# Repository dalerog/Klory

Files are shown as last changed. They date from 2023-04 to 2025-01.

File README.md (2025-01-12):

# Klory
A variation of the Klor keyboard by GEIGEIGEIST (https://github.com/GEIGEIGEIST/KLOR).

***

Finished Klory

## Introduction

This is a guide to my experiences buiding Klory, my variant of the Klor keyboard. This was my first keyboard build and GEIST did an outstanding job
documenting the build process in the GitHub repository. The changes I made were mainly due to my inexperince. Some were just personal preference 
differences.

Spoiler alert! I love Klory and am buiding a second for home.

## Thanks!

Of course, thanks to GEIST for making such a great keyboard. 

- Thanks to Char for leading me down the mechanical keyboard rabbit hole. 
- Thanks to Peter B. for help soldering diodes and hot swap sockets. 
- Thanks Harlan for expertise in all things maker.
- Thanks Rohit G for advice on standoffs.

## Why the Klor?

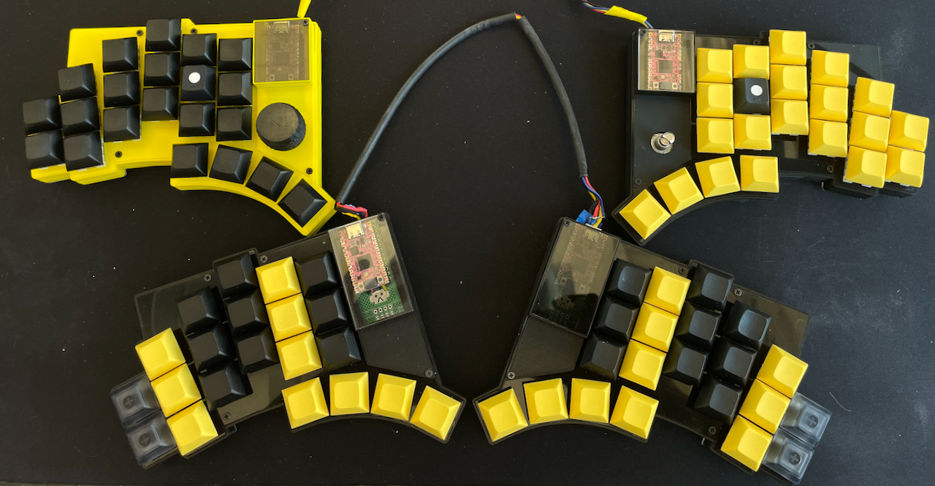
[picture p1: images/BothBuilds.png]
Both Builds


I was using a Planck Ez. I had changed the keymap to a 3x5 layout in which I was not using the center 6 keys above the spacebar. I was using the equivalent of four (4) thumb keys in my layout. However, I felt that my thumbs were cramped as they had to fold under my hand to get to some of the keys.

I really liked the Planck Ez, but then I started wanting a split keyboard. I originally looked for a split Planck, but then I thought column
stagger would be great and more room for my thumbs. I really liked the Corne, but I was using four thumb keys.

Therefore, the main reasons for the Klor were:
- four thumb keys
- thumb keys not requiring folding thumb under hand
- thumb keys in a curve

There were several nice to haves:
- encoder support
- the option of moving the pinkie out for the Q and P key instead of up.
- KB2040 support
- trackball support

I really wished the trackball was still for sale.

I was not interested in:
- OLED
- haptic feedback
- sound

These options did not seem that useful. Also, not all of the firmwares supported these different options.

I decided to built a wired Polydactyl using the Adafruit KB2040 without LEDs.

## Decisions

### Polydactyl

As I mentioned before, I picked the Klor for the four thumb keys. I was originally planning to build the Yubitsume layout without the extra pinkie keys. However, I was finding the pinkie reach to the P and the Q was not ideal. So, I decided to leave these keys on and experiment with using those keys as alternate pinkie keys. I have not started using these keys yet. Currently, I'm not interested in using these to give the pinkie more keys like return and delete etc. I'm more interested in fewer keys.

### LEDs

I really wanted the per key LEDs and partially decided on a wired solution to get the LEDs. However, after the initial excitment of having LEDs on the 
Planck, I decided that it didn't have a lot of value. I could't even see the leds in the lighting at work. I also wasn't sure which LEDs to order.

### Choc switches

The only negative at this point was that I wanted low profile Choc switches. I spent time looking for an alternative to the Klor that was low profile.
There were some teasers that there might be a low profile Choc variant. However, this did not seem likely or to happen in the timeframe I was willing to wait. I ended up decided that using MX switches allowed me to use the MX DSA keycaps that I had purchased for the Planck. I'm really happy that I went with MX switches because it gave me much more flexibility to test switches on the Planck.

### Why wired?

As a first build, I thought that a wired solution would be easier to debug and would have less failure modes. It would also work with QMK which I was used to using with the Planck. In addition, there were more options for MCUs and they would be cheaper.

There are cases where the right keyboard stops communicating with the left. Since, the keyboards are wired, I can just unplug them. I use a magnetic USB adapter so this is super easy to do. 

### KB2040

I decided to use the KB2040 from Adafruit. I picked it because it was cheap and and seemed very versatile. It worked with CircuitPython, C++, and Rust. It also had extra connectors, debug pins, LEDs, and reboot/reset buttons. It would be a great MCU for other projects if the keyboard didn't work out.

***

## Parts

Information about the parts I used and where I bought them is on the [Parts page](/pages/Parts.md).

## Build

Details about building my Klor keyboard are on the [Build page](/pages/Build.md).

## Building the Case

Details about building the case are on the [Case Build page](/pages/CaseBuild.md)

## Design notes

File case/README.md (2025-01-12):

# Case Source Files

This folder contains the files for building the case.

See case build documentation for more information.

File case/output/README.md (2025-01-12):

# STL Files for 3D Printing

This directory contains STL files for 3D printing that were exported from the OpenSCAD files in the parent directory.

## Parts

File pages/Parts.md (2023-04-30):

# Parts

Here is where I ordered the parts for my keyboard in the spring of 2023. This list will get stale overtime.

| Part Name | Vender | Notes |
| :--- | :--- | :--- |
| PCB  | [JLCPCB](https://jlcpcb.com) | I ordered a green PCB instead of a black one because it was 2+ days faster. Minimum order was 5. |
| MCU  | [Adafruit](https://www.adafruit.com/product/5302) | KB2040 |
| MX Key switch | Amazon | When you include shipping, you can get some better deals here than other vendors. But, I had to order 65. |
| switch socket | [Adafruit](https://www.adafruit.com/product/4958) | Kaihl Switch Socket|
| diodes 1N4148W| [Adafruit](https://www.adafruit.com/product/5099) | |
| 1u MX keycaps | [Adafruit](https://www.adafruit.com/product/4997) | DSA keycaps in multiple colors. |
| OLED module | N/A | Did not use. |
| reset button  | N/A | Did not use. The KB2040 has a reset button on it. Also, I was building a wired version and can just unplug it. |
| ~~TRRS jack~~ JST-SH Connector | [Adafruit](https://www.adafruit.com/product/4208) | Currently, hardwired, I have purchased this instead of TRRS. |
| ~~TRRS cable~~  JST-SH Cable | [Adafruit](https://www.adafruit.com/product/5385) | Currently, hardwired, but purchased this instead of TRRS. |
| EC11N1524402 encoder  | [Mouser](https://www.mouser.com/ProductDetail/Alps-Alpine/EC11N1524402?qs=W%2FMpXkg%252BdQ5mmk2EdvtXAA%3D%3D) | Planning to use this one, but have not installed it yet. |
| encoder knob  | N/A | Thinking of adapting the [Klotz Knob](https://github.com/GEIGEIGEIST/KLOTZ/tree/main/knob), but haven't yet. |
| USB cable | N/A | Using one I already had. I recommend a super flexible cable. Some usb-c video cables are too stiff. |

## OPTIONAL PARTS

I was going to use the pins that come with the KB2040 and these [headers from Adafruit](https://www.adafruit.com/product/598). However, I didn't think the combination worked that well. The headers while shorter than normal are still a little tall and the pins are a little long for them.

I ended up ordering these sockets from [TyperActive](https://typeractive.xyz/products/ez-machine-sockets-and-headers). They are expensive when you consider that the KB2040 itself is a $1 cheaper. However, they work well. I highly recommend getting sockets as I it nice being able to remove the MCU when you want to make a mod to your PCB. I was thinking that I could just unsolder the sockets if I wanted to move them to another board, but It isn't that easy to unsolder. I am a novive at desoldering though. Order a couple of extras and get free shipping.

## Case Parts

I printed my own 3D parts and cut my own acrylic. I ended up making very different cases which I will detail later. Here are the parts I ordered:

| Part Name | Vender | Notes |
| :--- | :--- | :--- |
| M2 Screws | [Amazon](https://a.co/d/6NNHfAM) | Lots of different sizes of screws gave me flexibilty when I designed my own case |
| Bass Standoffs in mutiple sizes | [Amazon](https://a.co/d/2GAflAl)  | |
| Bass Standoffs - 7mm | [Amazon](https://a.co/d/j9lGEjD)  | |

After I made my Amazon orders, I ended up finding standoffs at [Keeb.io](https://keeb.io/collections/diy-parts/products/m2-screws-and-standoffs). I haven't ordered these, but have ordered other items from Keeb.io.

***

[Back to Main Page](/README.md)

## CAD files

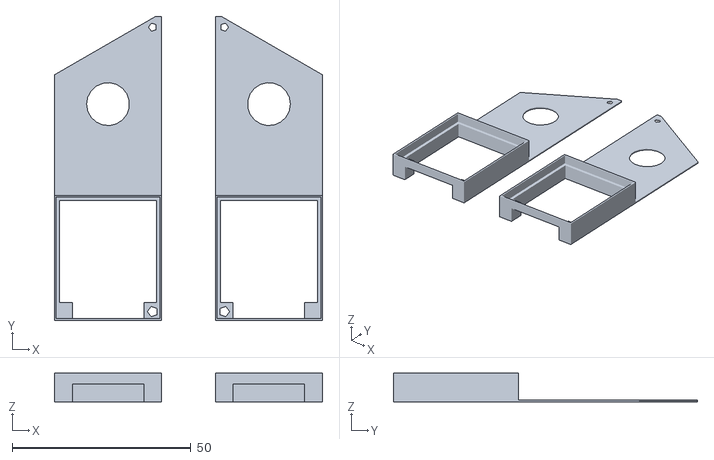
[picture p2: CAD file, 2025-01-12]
case/output/mcuCoverTopLessWithEncoder.stl
75.0 x 85.0 x 8.00

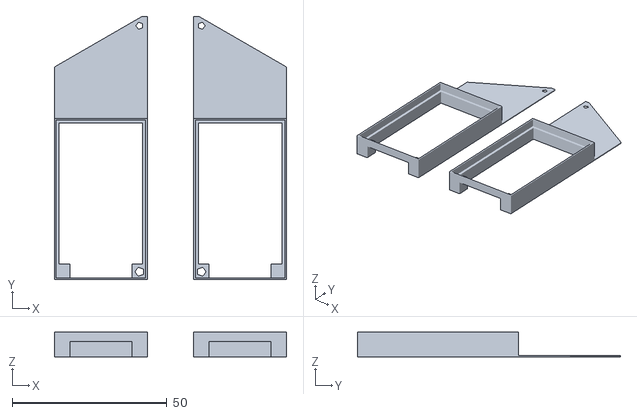
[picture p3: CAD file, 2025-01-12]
case/output/mcuCoverTopless.stl
75.0 x 85.0 x 8.00

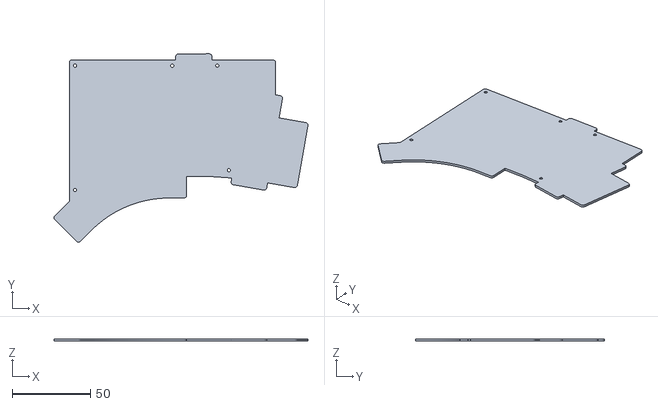
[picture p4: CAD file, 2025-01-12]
case/output/bottomPlate.stl
162.1 x 120.3 x 1.50

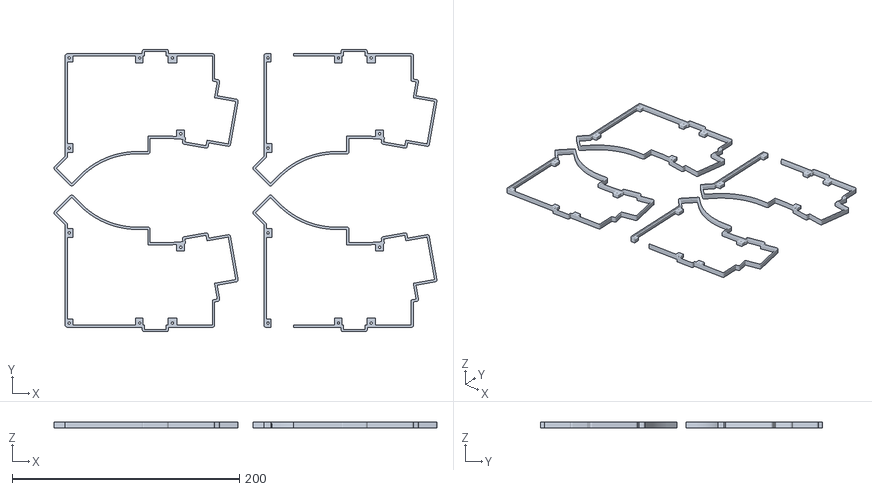
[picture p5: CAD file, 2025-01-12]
case/output/caseSides.stl
337.1 x 248.7 x 5.50

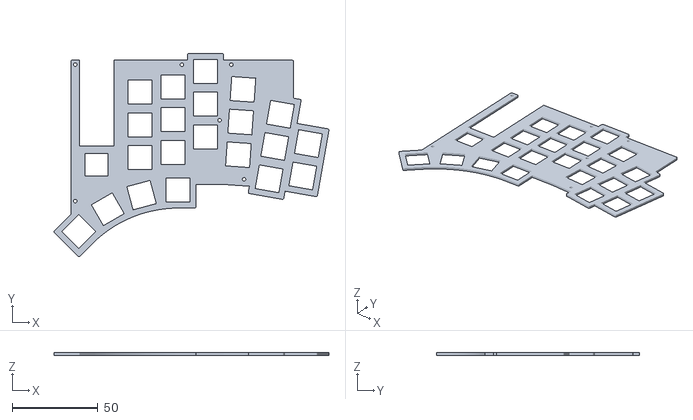
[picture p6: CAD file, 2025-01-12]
case/output/switchPlate.stl
160.0 x 118.2 x 1.50

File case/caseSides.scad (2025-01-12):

/* Copyright 2024
 * Dale Rogerson
 *
 * This program is free software: you can redistribute it and/or modify
 * it under the terms of the GNU General Public License as published by
 * the Free Software Foundation, either version 2 of the License, or
 * (at your option) any later version.
 *
 * This program is distributed in the hope that it will be useful,
 * but WITHOUT ANY WARRANTY; without even the implied warranty of
 * MERCHANTABILITY or FITNESS FOR A PARTICULAR PURPOSE.  See the
 * GNU General Public License for more details.
 *
 * You should have received a copy of the GNU General Public License
 * along with this program.  If not, see <http://www.gnu.org/licenses/>.
 */

//---  Top plate
module topPlate() {
    linear_extrude(height = 1.5)
    import("SwitchPlate.svg");
}

//---  Bottom plate
module bottomPlate() {
    linear_extrude(height = 1.5)
    import("BottomPlate.svg");
}

//---  Top outline
/*
linear_extrude(height = 1.5)
import("outerLip.svg");
*/

module rightSide() {
//--- Side
sideHeight = 4;
linear_extrude(height = sideHeight)
import("side.svg");

//  Lip from top outline
dY = 0.25;
lipHeight =  1.5 + dY;
lipZ = sideHeight - dY;
translate([0, 0, lipZ])
linear_extrude(height = lipHeight)
import("outerLip.svg");
}


module leftSide() {
    mirror([0, 1, 0]) {
        rightSide();
    }
}

//--- Make hole for the usb and keyboard connectors
module rightSideWithHole() {
    difference() {
        rightSide();
        translate([15, 108, -1]) cube([20, 15, 9]);
    }
}

module leftSideWithHole() {
    mirror([0, 1, 0]) {
        difference() {
            rightSide();
            translate([15, 108, -1]) cube([20, 15, 9]);
        }
    }
}

// Render the case for the right side with a hole for the connector.
rightSideWithHole();

// Uncomment this if you want to see how the bottom plate fits with the top plate.
// You can also print the bottom plate instead of cutting it out of acrylic with a laser cutter.
//bottomPlate();

// Uncomment to show top plate fitting on top of the case.
// You can also use this to print the top plate intead of cutting with a laser cutting. 
// Remove the translatoion for printing.
//translate([0, 0, 4]) topPlate();

translate([-175, 0, 0]) rightSide();


translate([0, -10, 0]) leftSideWithHole();
translate([-175, -10, 0]) leftSide();

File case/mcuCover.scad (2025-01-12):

/* Copyright 2024
 * Dale Rogerson
 *
 * This program is free software: you can redistribute it and/or modify
 * it under the terms of the GNU General Public License as published by
 * the Free Software Foundation, either version 2 of the License, or
 * (at your option) any later version.
 *
 * This program is distributed in the hope that it will be useful,
 * but WITHOUT ANY WARRANTY; without even the implied warranty of
 * MERCHANTABILITY or FITNESS FOR A PARTICULAR PURPOSE.  See the
 * GNU General Public License for more details.
 *
 * You should have received a copy of the GNU General Public License
 * along with this program.  If not, see <http://www.gnu.org/licenses/>.
 */


//---  Top plate
module topPlate() {
    linear_extrude(height = 1.5)
    import("top-thisIsSwitchPlate.svg");
}

// --- This mcu cover has a top on it and is the same height down the keyboard. I did not use
module mcuCover() {
     difference() {
        cube([30, 85, 5]); // main body
        translate([5, 0, 0]) cube([20, 60, 4]); // main hollow out
        translate([5, 0, 0]) cube([15, 70.75, 4]); // back middle hollow out
        translate([2, 7, 0]) cube([10, 71, 4]); // left wider hollow out
        translate([20, 7, 0]) cube([8, 60, 4]); // right wider hollow out
      
     color("green")
        translate([0, 86, 0])
            rotate([0, 0, -30])
                cube([40, 40, 5]); // trim end
    color("green") // front hole
        translate([2.5, 2.5, -5]) cylinder(h = 10, r = 1.2);
    color("green") // back hole
        translate([2.5, 2.5+79.5, -5]) cylinder(h = 10, r = 1.2);

    color("green") // light hole
        translate([10, 2.5, -5]) cylinder(h = 15, r = 1.2);
    color("green") // light hole
        translate([20, 2.5, -5]) cylinder(h = 15, r = 1.2);
    }
}


/* Uncomment these lines to use this alternative cover.
translate([5, 0, 5])
    rotate([0, 180, 0])
        mirror([1, 0, 0])
            mcuCover();
 

translate([-5, 0, 5])
    rotate([0, 180, 0])
        mcuCover();
*/  

topPlateHeight = 3.0;

mcuClearance = 5;
coverHeight = mcuClearance + topPlateHeight;

coverWidth = 30;
// coverLength = 52;

lipWidth = 0.5;
  
wideWallWidth = 5;
thinWallWidth = 1.5;

postOffset = 5;

//--- Make a cover that has minimal height and an opening to see MCU.
module mcuCoverTopless(CoverLength) {
    //  Front
    difference() {
        cube([coverWidth, CoverLength, coverHeight]); // front body
        
        translate([wideWallWidth, 0, 0])
            cube([coverWidth-wideWallWidth*2, CoverLength-thinWallWidth, mcuClearance]); // main hollow out
        
        translate([lipWidth, lipWidth, mcuClearance])
            cube([coverWidth-lipWidth*2, CoverLength-lipWidth*2, topPlateHeight]); // remove top

        translate([thinWallWidth, postOffset, 0])
            cube([5, CoverLength-thinWallWidth-postOffset, coverHeight]); // make outside wall narrower
            
        translate([coverWidth-postOffset-thinWallWidth, postOffset, 0])
            cube([5, CoverLength-thinWallWidth-postOffset, coverHeight]); // make inside wall narrower                
                
    color("green") // front hole for screw/support
        translate([2.5, 2.5, -5]) cylinder(h = 10, r = 1.5);

    }
    
    //  Back half
    difference() {
        color("blue") translate([0, CoverLength, 0]) cube([30, 52-CoverLength+33, .5]); // front body
        
      
     color("green")
        translate([0, 86, 0])
            rotate([0, 0, -30])
                cube([40, 40, 5]); // trim end

     color("green") // back hole
        translate([2.5, 2.5+79.5, -5]) cylinder(h = 10, r = 1.2);
                
    }
}


// --- Covers the hole in the top plate.
//
//     This can be cut on a laser cutter instead of 3D printed which is what I did.
module topInsert(CoverLength) {

    difference() {
        translate([lipWidth, lipWidth, mcuClearance])
            cube([coverWidth-lipWidth*2, CoverLength-lipWidth*2, topPlateHeight]); // remove top
        
        color("green") // front hole
            translate([2.5, 2.5, -5]) cylinder(h = 10, r = 1.2);
    }
};

coverLength = 52;

//
// These print without the holes for the encoder. 
//

// Left Cover
//mcuCoverTopless(coverLength);

// Right Cover
//translate([-coverWidth/2, 0, 0]) mirror([1, 0, 0]) mcuCoverTopless(coverLength);

// If you don't want to do that you can uncomment these lines and cover the hole in the
// MCU cover. You will need to adjust it to get it to work for both right and left covers and
// add screw holes.
// color("green") topInsert(coverLength); // This covers the hole in the mcu cover


coverLengthWithEncoder = 35;

module mcuCoverToplessEncoder() {
    difference() {
        mcuCoverTopless(coverLengthWithEncoder);

        // This is the hole for the encoder to poke through.
        color("green") // front hole
            translate([coverWidth/2, 60.5, -5]) cylinder(h = 10, r = 6);
    }        
}

//
// These print with the hole for the encoder. If you aren't using the encoder. Look above.
//

// Left cover
mcuCoverToplessEncoder();

// Right cover
translate([-coverWidth/2, 0, 0]) mirror([1, 0, 0]) mcuCoverToplessEncoder();

// I put clear or smokey arcylic over the MCU so that I can see it. Looks really cool.
// If you don't want to do that you can uncomment these lines and cover the hole in the
// MCU cover. You will need to adjust it to get it to work for both right and left covers
// and add screw holes.
// color("green") topInsert(coverLengthWithEncoder); // This covers the hole in the mcu cover


// put switch plate down to align the hole in the encoder.
/*
translate([-10, 114, 0]) {
    mirror([0, 1, 0]) {
        topPlate();
    }
 } 
 */
     
 

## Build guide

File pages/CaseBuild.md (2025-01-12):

# Building the Case

As you know from the other sections, I moved the position of the MCU from the bottom to the top of the PCB. This means that I have to change the case to
adjust to this change. There are a set of changes that need to be made to made the original case work with the moved MCU. These include moving the hole in
the case for the USB connector, covering up the holes for the Reset and TRRS, making a hole in the switchplate for the MCU, and covering the hole in the
bottom for the MCU to fit. In addition, the Klor case has a plate that fits over the switch plate. This plate will not fit over the MCU in the position on top.

However, I ended up with a bigger issue. It is probably either due to me doing something wrong or to the hotswap sockets that I used, but in my case build
the distance between the PCB and the switchplate was too small. The keyswitches would not fully snap into the switchplate. Also when you tried to pull the 
switches out, the switchplate would move up as you pulled up.

As a result, I essentially redesigned the case. 

## Overview

The new case is essentially a stack case and is a combination of 3D printed and laser cut. It ends up slightly smaller and shorter than the orginal case.

I limited myself to using the existing holes in the PCB and not drilling new holes. It would have been nice if the holes in the PCB were for M2 screws
instead of M2 standoffs, but we got it to work.

Here are the pieces to the case.

| Part | Build | Details | Notes |
| --- | --- | --- | --- |
| Bottom Plate | laser cut 1.6 mm acrylic or 3D printed | This piece is smaller than in the original Klor case. There are holes for M2 screws. | I laser cut mine from clear acrylic scrap |
| Side Plate no hole | 3D printed | There are holes for M2 standoffs 9mm. | It has an "h" profile for the PCB to rest on. |
| PCB | | The PCB also has holes for the M2 standoffs. | |
| Side Plate with hole | 3D printed | Hole is for the usb and TRRS connectors to go through | It also has an "h" profile for switchplate to rest on. |
| Switchplate | 1.6 mm acrylic or 3D printed | Have cutouts for the MCU to poke up through | I did both acrylic and 3D printing versions |
| MCU Cover Frame | 3D Printed | This is a frame to hole a cover for the MCU. It also covers the encoder hole. | |
| MCU Cover | Laser Cut | Covers the MCU. | You could 3D print this with the part abhove. |

The source files for building the case can be found in the case folder. 

* If you are laser cutting the switch plate (top) and bottom plate, you can use the files **BottomPlate.svg** and **SwitchPlate.svg**. 

* The file **caseSides.scad** is an OpenSCAD file for generating the STL files for 3D printing the case. This one file will generate the four parts of the case that are needed. You can comment out lines if you only want to print one part at a time. 

* The file **output/caseSides.stl** is the file for the 3D printer that was exported from **caseSides.scad**.

* If you want to 3D print the top and bottom plate instead of laser cutting them, you can uncomment lines in caseSides.scad to generate them. You can find the output for these in the files **case/switchPlate.stl** and **case/bottomPlate.stl**. I didn't use these files in my build and it is possible that the height of these files are not the same as the acrylic that I used, so it might take some adjustment to work.

* The file **mcuCover.scad** creates the cover for the MCU and encoder. There are multiple versions that you can create from this file depending on what you comment or uncomment. The file **case/mcuTopless.stl** is the output for a build without an encoder while **case/mcuTopLessWithEncoder.stl** is for builds with an encoder.

    * These version do not have covers over the MCU, but require an acrylic window. You can uncomment some lines in the scad file to get          covers 3D printed. You would need to add screw holes as I didn't add those. You can always use a drill to add them.
 
* If you are laser cutting acrylic for a window to see the MCU, use the files **mcuCoverInsert.svg** or **mcuCoverInsertWithEncoder.svg**. I used both clear and smoke acrylic and can't decide which looks better. Both look awesome!

***

## Building

| Parts for the case |
|:--:| 
| *Parts of the case except for the MCU cover.* |

The key design element of this case is that the distance between the PCB and the switchplate is fixed. The "h" shaped side pieces are what makes this 
happen.

| Case side |
|:--:| 
| *Case side.* |

| Closeup of case side |
|:--:| 
| *Closeup of case side.* |

| Case Bottom |
|:--:| 
| *Here is the case bottom with the standoffs attached. (These standoffs are too short.)* |

| Case Bottom with Side Attached |
|:--:| 
| *Case bottom with the side attached.* |

| PCB mounted on the bottom side. |
|:--:| 
| *PCB mounted on the bottom side.* |

| Closeup of PCB on case side |
|:--:| 
| *Closeup of PCB on top of case side.* |

| Second side piece installed |
|:--:| 
| *Second side piece installed on top of the PCB.* |

| Switchplate installed |
|:--:| 
| *Switchplate installed.* |

| Keyswitches installed |
|:--:| 
| *Keyswitches installed.* |

| Keycaps Installed |
|:--:| 
| *Keycaps installed* |

## MCU Cover

There are too designs for the MCU cover. One with no hole for the encoder and one with the encoder hole. The one for the encoder has a smaller cover for
the MCU. You could modify the non-encoder version to have the smaller cover if you wanted.

Here is a view of the switch plate and the mcu cover.

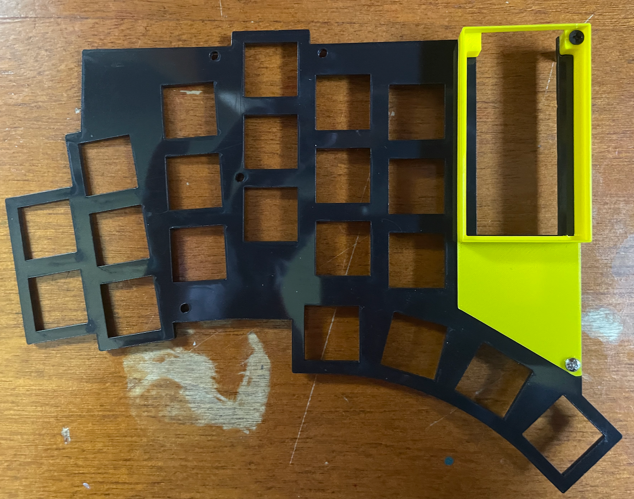
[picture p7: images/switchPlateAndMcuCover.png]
Switch plate and MCU cover
|  |
|:--:|
| **Switch plate and MCU cover** |

This image shows the mcu covers and the acrylic windows to go over the MCUs.

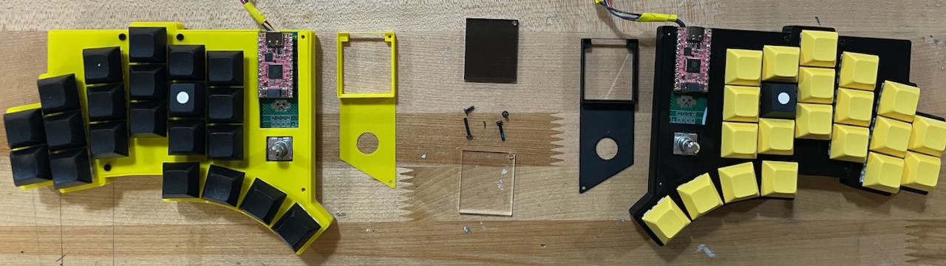
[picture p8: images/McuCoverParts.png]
MCU cover and acrylic windows
|  |
|:--:|
| **MCU cover and acrylic windows** |

***

## Finished Views

Here are some photos of the finished keyboards.

### Finished Bottom View

I chose to use clear acrylic for the bottom which really shows off the PCB. This is great when people are asking you about the keyboard.

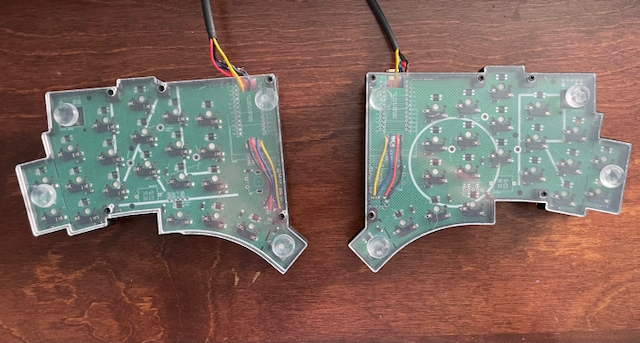
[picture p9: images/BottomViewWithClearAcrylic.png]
Finished Bottom View
|  |
|:--:| 
| *Bottom view with clear acrylic* |

### Clear vs Smoke MCU Window

| Finished Klory |
| :--: |
| *Clear and Smoke MCU Windows* |

***

### Encoder Knobs

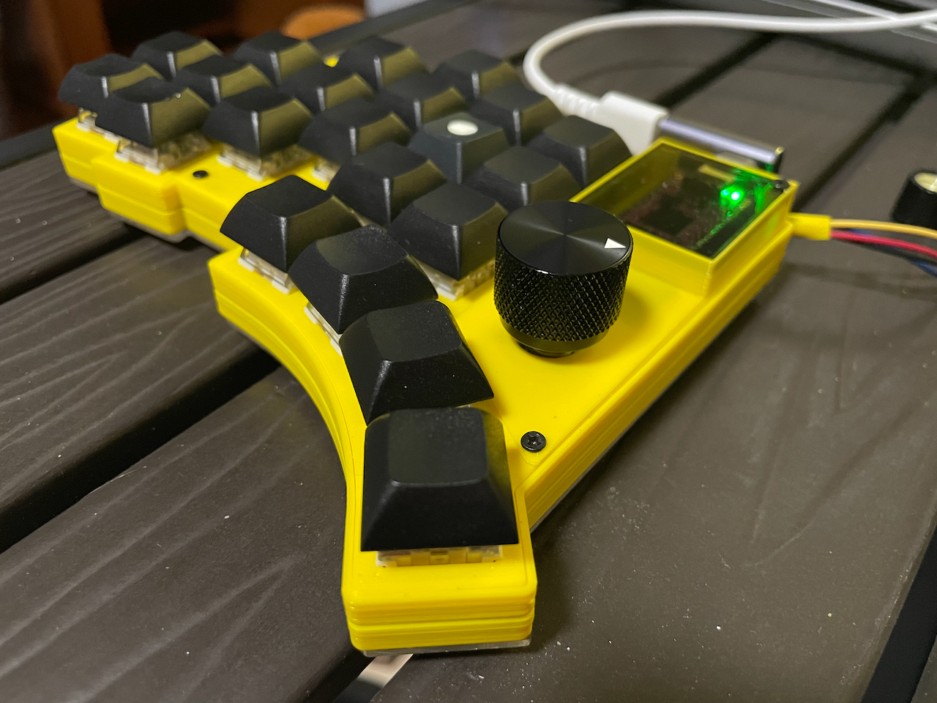
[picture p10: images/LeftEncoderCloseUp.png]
Left encoder knob close up
|  |
| :--: |
| *Left encoder knob close up* |

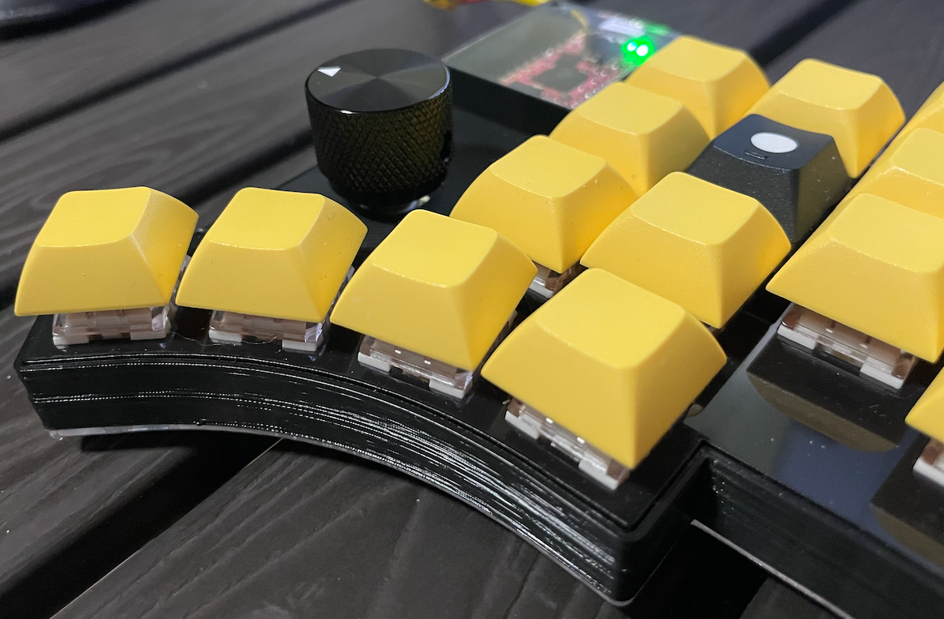
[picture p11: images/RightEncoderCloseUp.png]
Right encoder knob close up
|  |
| :--: |
| *Right encoder knob close up* |
***

### Two Builds

| Two completed builds |
| :--: |
| *Two completed builds* |

***

[Back to Main Page](/README.md)

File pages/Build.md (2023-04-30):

# Build

This section goes into details about the process of building Klory.

## PCB

A ordered the PCB from [JLCPCB](https://jlcpcb.com). It was by far the cheapest option. I ordered the PCB in green instead of black as it would shorten
the build time by 2 days. I asked the support on JLCPCB if this would be okay and they said that it would.

The minimal order was 5 pcbs. I did not like the idea of having enough PCBs for 2.5 keybaords. I did some mockups in KICAD to see if I could get two PCBs
on a single file, but the cost ended up being the same as ordering 10 pcbs. So, I went with the standard PCB. 

The first PCB I soldered didn't work completely correctly. All the keys worked, except for the thumb keys. They would register as all of the keys in the
row and not just the thumbkey. I did a lot of debugging. All of the diodes were correct as far as I could determine. There is a possibility that it is a 
grounding issue. So, in the end the extra PCB turned out to be a good idea. I built too complete keyboards from the other four PCBs.

| Bare PCB |
|:--:| 
| *Bare PCB* |

## Diodes and Kaihl Sockets

Soldering the diodes and the sockets was fairly easy. For the diodes, I would put down a little flux, put solder on the iron, and bring the solder to the
diode while holding it down with tweezers. Sockets were done in the same way. They sockets are easier in that they sit nicely in the holes on the board. I
still pushed down on them with the tweezers just to make sure they were flush.

The circuit board is printed to show the correct location for the sockets and the correct direction for the diodes. This is a big help.

| Diodes |
|:--:| 
| *The diodes are really small!* |

| PCB with diodes soldered on |
|:--:|
| *Here is the PCB with diodes soldered to it.* |

| PCB with sockets soldered |
|:--:|
| *Now the PCB has the Kaihl switch sockets soldered to it.* |

## MCU

The original design of the Klor has the MCU mounted to the bottom of the circuit board. The case designs have a cut out for the MCU to hang down. I didn't
really like this design. I wanted the MCU to be better protected. I also wanted to be able to access the boot and reset buttons on the KB2040.

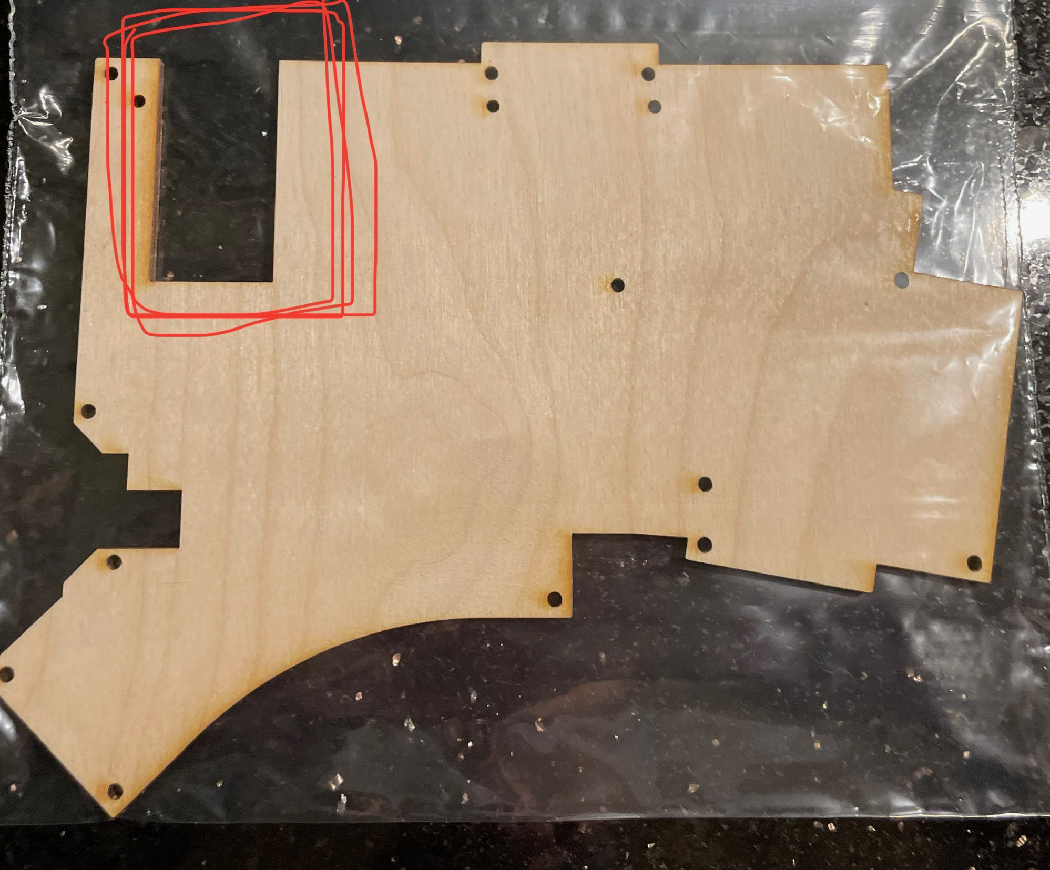
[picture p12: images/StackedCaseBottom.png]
Stacked case bottom showing cut out for MCU

|:--:| 
| *This is the laser cut buttom plate of the original case (in wood) showing the cut out for the MCU.* | 

I started playing around in KiCAD to figure out how to mount the MCU on the top. However, the MCU is actually mounted right side up to the bottom of the
keyboard. This means that the circuit board does not need to be redesigned to mount the MCU to the top. You just put the sockets on the top of the board.

Since the board is double sided there are two possible locations for the sockets. I put the sockets on the bottom of the board like the original build
directions say. I would then look at the top of the board to see where the pins would poke through. Then I would switch the socket to the top of the board
and solder it into place.

Mounting the MCU to the top of the PCB meant that the original cases would need to be redesigned. 

After mounting the MCU to the top of the board, I discovered that having the MCU mounted right side up to the bottom of the PCB is a normal design. One
of my co-workers has a keyboard with a similar design.

| MCU and sockets attached |
|:--:| 
| *Showing the MCU attached to the socket on the left and the MCU sockets on the right.* |

After attaching the MCU, you can insert some switches and make sure everything is working. For a couple of the PCBs, I had to resolder a couple of the
sockets to get a better connection.

| Testing the Kaihl Box Navy switches |
|:--:|
| *Testing the switches* |

## TRRS

I did not want to use the typical microphone/headset cable for communication between the keyboard halfs. I don't have a great reason for this, but I don't
like using a connector for a different purpose. There is also the case that as you pull the cable out power could be sent through one of the other
wires in the cable. The chance of that is most likely pretty small, but still it seems a little hacky.

I decided to use the JST-SH Connector. These things are crazy small and I couldn't solder wires to them at all. They really need a breakout board. :-(

| JST-SH Connector |
|:--:|
| *Small JST-SH Connector* |

I'm not sure what I'm going to use instead. I might go back to the microphone/headset style cable. I'm also looking at magnetic connectors that Adafruit
sells, but they are fairly big. [Magnetic connectors](https://www.adafruit.com/product/5358)

I also did not like where the TRRS socket was mounted. While the mounting location is typical of most split keyboards, I want to have my mouse between
the keyboard halves and felt like the original location had the cable coming out into the area where my mouse should be. I decided to use wires to route
the socket to come out under the MCU in the same location as the USB connector. I feel like this is a much better location. 

Currently, the two halfs of both of my keyboards are hardwired. It is not very elegant, but it works.

My original plan for my first keyboard was to solder wires to the TRRS pads. These were going to be soldered to the bottom of the PCB because that is
where the TRRS jacks are mounted and the wires also need to be out of the way of the encoders. I then was going to solder these wires to the JST-SH
connector under the MCU. However, the wires need to get to the other side of the board.

So, I **drilled holes** in the board to make this happen! That was rather scary. It looks pretty cool though. :-)

However, there is a cutout in the PCB for the USB socket to sit. For the second build, I decided I could route the wires through this cutout instead of
drilling holes in the PCB. That seems like a much better idea.

| Wires soldered to TRRS pads and holes for wires in PCB |
|:--:|
| *Wires soldered to TRRS pads and holes for wires in PCB* |

| Wires soldered to TRRS pads |
|:--:|
| *Wires soldered to TRRS pads* |

| Hard wired halves top view |
|:--:|
| *Hard wired halves top view* |

| Hard wired halves bottom view |
|:--:|
| *Hard wired halves bottom view* |

Notice that the cable between the halves goes up and over to the other half. It is out of the way of where the mouse would be. I think this change is
great. It will be even better when I have a connector and it isn't hard wired.

## Encoders

I've been using my first Klor keyboard for about a month without the encoders installed as I ordered them late. I just finished my second build and did
install the encoders on that keyboard. I hope to put the encoders on the first keyboard soon. Probably after I figure out which knobs I want to use.

The encoders snap into the board very securely. It is a really nice fit. Soldering them is easy.

| Encoders Attached |
|:--:|
| *Encoder soldered onto PCB* |

***

[Back to Main Page](/README.md)

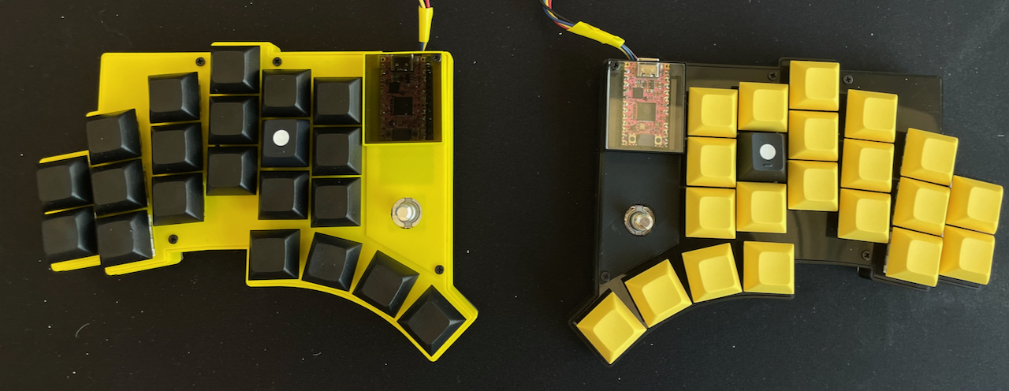
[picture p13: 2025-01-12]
images/SecondBuild.png

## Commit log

2023-04-23 Update README.md
    Added section on wired and MCU.
2023-04-23 Update README.md
    Added information about the reset button.
2023-04-23 Update README.md
    Added section on MCU sockets.
2023-04-23 Update README.md
    Added section on PCB.
2023-04-23 Add files via upload
    Add photo of bare PCB.
2023-04-24 Update README.md
    Added information about the case parts that I ordered.
2023-04-28 Update README.md
    Added information on Diodes, Sockets, and MCU.
2023-04-28 Add files via upload
    Images for Diodes and MCU sections.
2023-04-28 Update README.md
    Information about the TRRS cables.
2023-04-28 Update README.md
    Mentioned testing the switches.
2023-04-28 Add files via upload
    Added file showing the switches installed right after the MCU.
2023-04-28 Update README.md
    Fixed filename for testing the switches.
2023-04-30 Added encoder information
2023-04-30 Added image showing encoder soldered on PCB
2023-04-30 Add link to the Case Build page.
2023-04-30 Start filling in the case information.
2023-04-30 Added files for the case build.
2025-01-12 Create README.md for case files
2025-01-12 Add information about the case source files.
2025-01-12 Added pictures of the encoders
